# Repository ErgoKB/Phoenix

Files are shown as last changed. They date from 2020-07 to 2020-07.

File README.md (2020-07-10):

# Phoenix

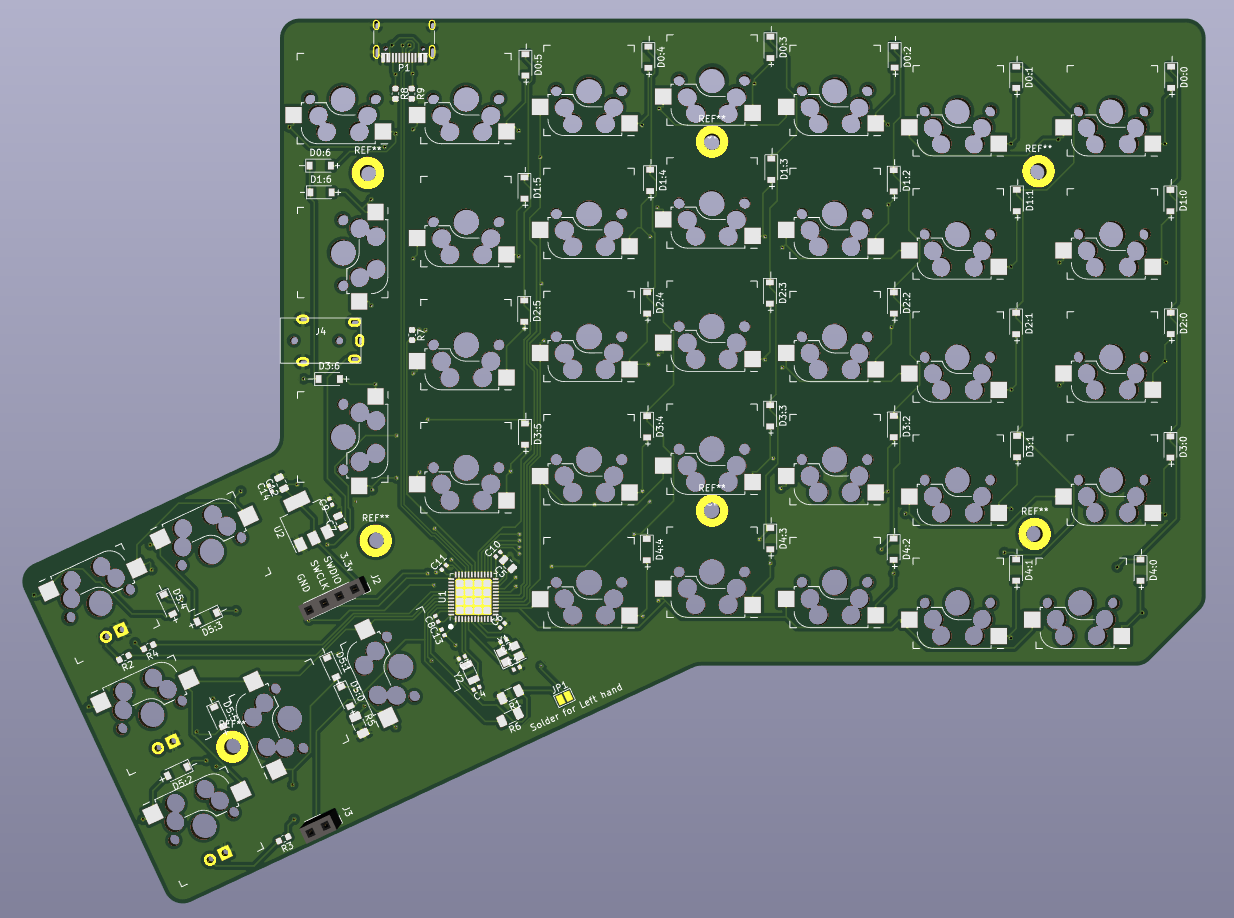
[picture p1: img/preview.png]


Phoenix is inspired by [Ergodox](https://www.ergodox.io/), and add several improvements on it.

## Features

* A split ergonomic keyboard which fits the shape of the hands of human
* Improve the keyboard performance and response time of Ergodox by using dual controller
* Dual connectivity of both left and right hands can connect to USB host without re-program the mcu
* Use USB C connectors
* Use hotswap switch connectors to get rid of soldering
* A single PCB design for both left and right hand
* A more stable PCB mounting design
* Use parts that are can be obtained more easily

## How to build

Still in progress

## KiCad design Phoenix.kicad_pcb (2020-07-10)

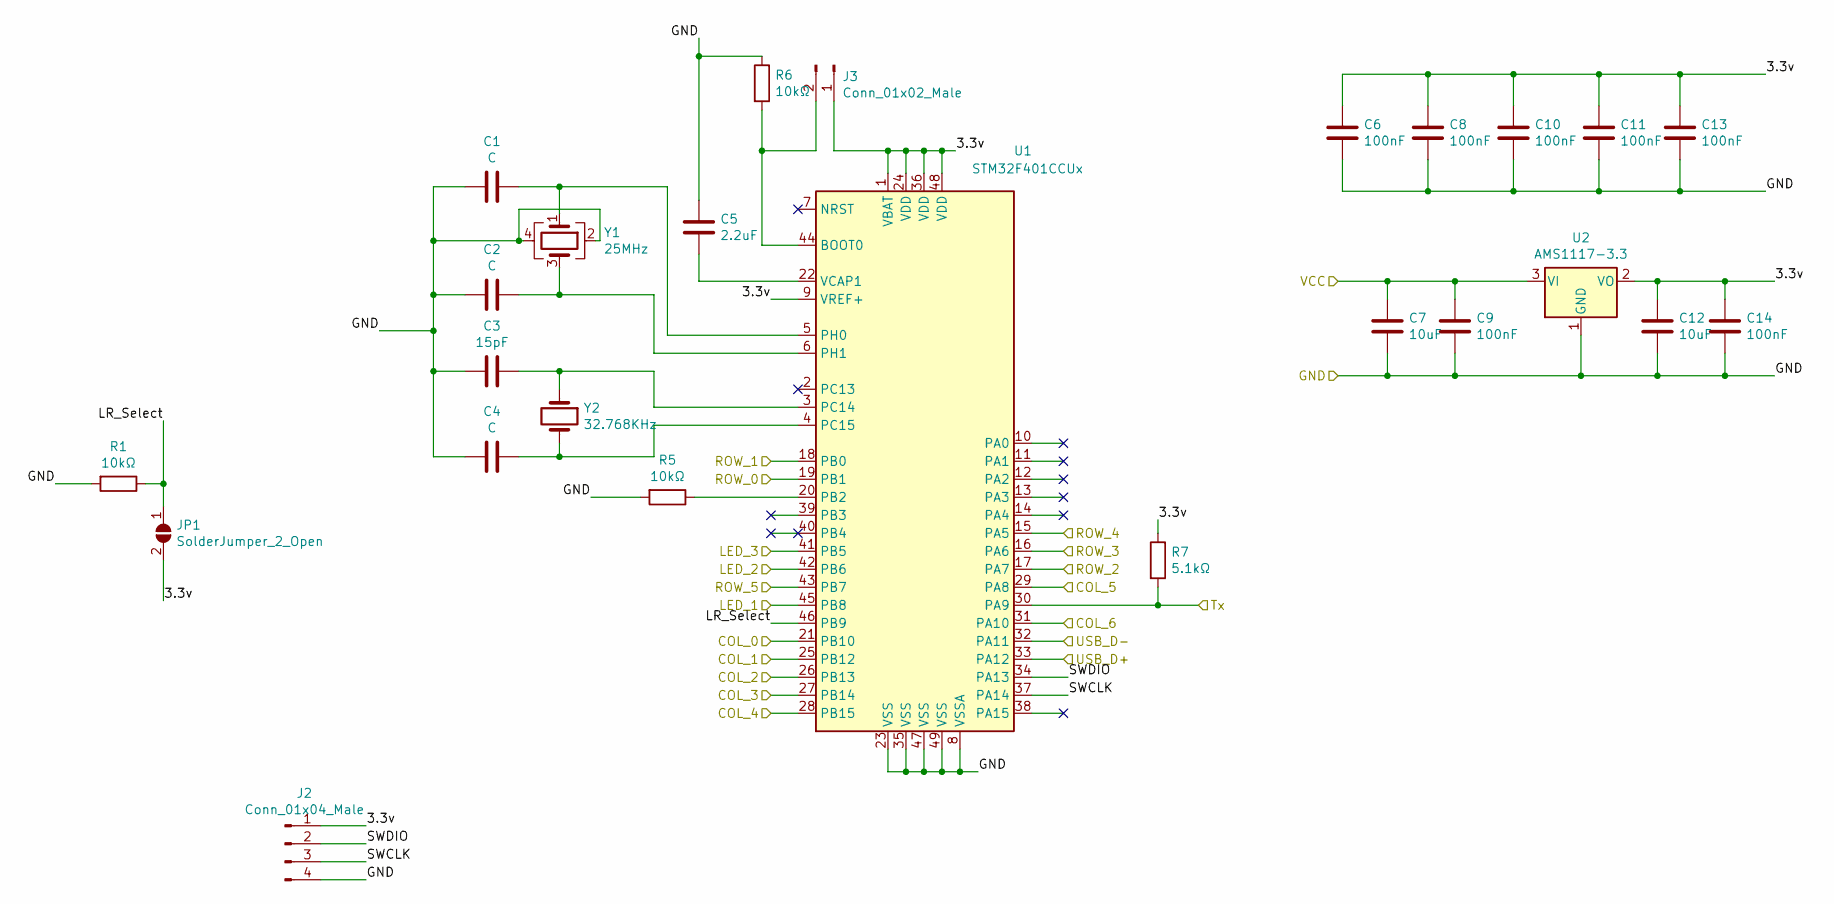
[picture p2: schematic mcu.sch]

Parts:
C1, C2, C4: C; C_0402_1005Metric
C3: 15pF; C_0402_1005Metric
C5: 2.2uF; C_0805_2012Metric
C6, C8, C9, C10, C11, C13, C14: 100nF; C_0402_1005Metric
C7, C12: 10uF; C_0805_2012Metric
J2: Conn_01x04_Male; PinSocket_1x04_P2.54mm_Vertical
J3: Conn_01x02_Male; PinSocket_1x02_P2.54mm_Vertical
JP1: SolderJumper_2_Open; SolderJumper-2_P1.3mm_Open_Pad1.0x1.5mm
R1, R5, R6: 10kΩ; R_1206_3216Metric
R7: 5.1kΩ; R_0603_1608Metric
U1: STM32F401CCUx; QFN-48-1EP_7x7mm_P0.5mm_EP5.6x5.6mm
U2: AMS1117-3.3; SOT-223-3_TabPin2
Y1: 25MHz; Crystal_SMD_3225-4Pin_3.2x2.5mm
Y2: 32.768KHz; Crystal_SMD_3215-2Pin_3.2x1.5mm

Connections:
/TRS/Tx: R7.2, U1.30 (PA9); also elsewhere on the board
/TRS/VCC: C7.1, C9.1, U2.3 (VI); also elsewhere on the board
/keyboard_matrix/COL_0: U1.21 (PB10); also elsewhere on the board
/keyboard_matrix/COL_1: U1.25 (PB12); also elsewhere on the board
/keyboard_matrix/COL_2: U1.26 (PB13); also elsewhere on the board
/keyboard_matrix/COL_3: U1.27 (PB14); also elsewhere on the board
/keyboard_matrix/COL_4: U1.28 (PB15); also elsewhere on the board
/keyboard_matrix/COL_5: U1.29 (PA8); also elsewhere on the board
/keyboard_matrix/COL_6: U1.31 (PA10); also elsewhere on the board
/keyboard_matrix/LED_1: U1.45 (PB8); also elsewhere on the board
/keyboard_matrix/LED_2: U1.42 (PB6); also elsewhere on the board
/keyboard_matrix/LED_3: U1.41 (PB5); also elsewhere on the board
/keyboard_matrix/ROW_0: U1.19 (PB1); also elsewhere on the board
/keyboard_matrix/ROW_1: U1.18 (PB0); also elsewhere on the board
/keyboard_matrix/ROW_2: U1.17 (PA7); also elsewhere on the board
/keyboard_matrix/ROW_3: U1.16 (PA6); also elsewhere on the board
/keyboard_matrix/ROW_4: U1.15 (PA5); also elsewhere on the board
/keyboard_matrix/ROW_5: U1.43 (PB7); also elsewhere on the board
/mcu/3.3v: C6.1, C8.1, C10.1, C11.1, C12.1, C13.1, C14.1, J2.1, J3.1, JP1.2 (B), R7.1, U1.1 (VBAT), U1.9 (VREF+), U1.24 (VDD), U1.36 (VDD), U1.48 (VDD), U2.2 (VO)
/mcu/LR_Select: JP1.1 (A), R1.1, U1.46 (PB9)
/mcu/SWCLK: J2.3, U1.37 (PA14)
/mcu/SWDIO: J2.2, U1.34 (PA13)
/usb_c/D+: U1.33 (PA12); also elsewhere on the board
/usb_c/D-: U1.32 (PA11); also elsewhere on the board
GNDPWR: C1.2, C2.2, C3.2, C4.2, C5.2, C6.2, C7.2, C8.2, C9.2, C10.2, C11.2, C12.2, C13.2, C14.2, J2.4, R1.2, R5.2, R6.1, U1.8 (VSSA), U1.23 (VSS), U1.35 (VSS), U1.47 (VSS), U1.49 (VSS), U2.1 (GND), Y1.2, Y1.4; also elsewhere on the board
unnamed: C1.1, U1.5 (PH0), Y1.1
unnamed: C2.1, U1.6 (PH1), Y1.3
unnamed: C3.1, U1.3 (PC14), Y2.1
unnamed: C4.1, U1.4 (PC15), Y2.2
unnamed: C5.1, U1.22 (VCAP1)
unnamed: J3.2, R6.2, U1.44 (BOOT0)
unnamed: R5.1, U1.20 (PB2)

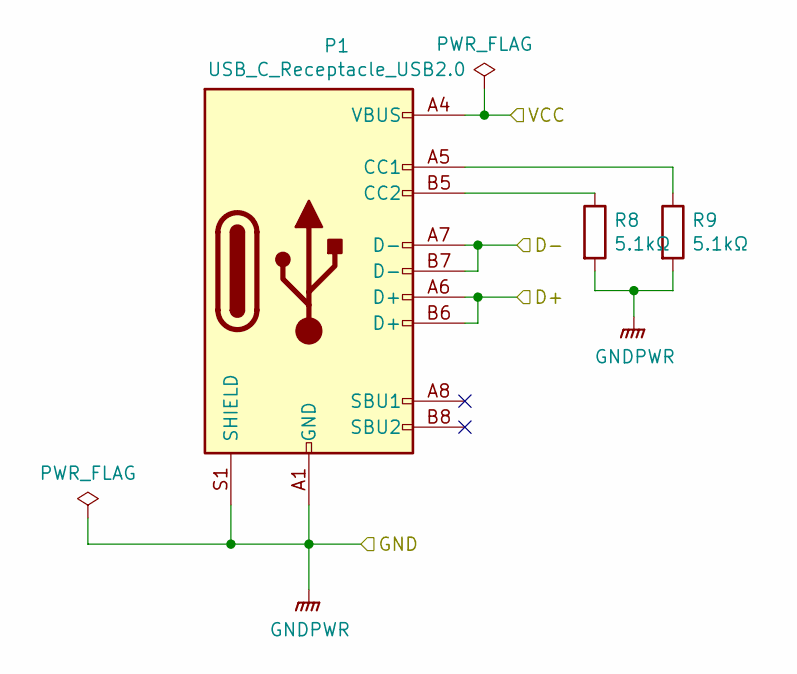
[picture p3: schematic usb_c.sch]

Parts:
P1: USB_C_Receptacle_USB2.0; USB_C_Receptacle_HRO_TYPE-C-31-M-12-Dual
R8, R9: 5.1kΩ; R_0603_1608Metric

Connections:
/TRS/VCC: P1.A4 (VBUS), P1.A9 (VBUS), P1.B4 (VBUS), P1.B9 (VBUS); also elsewhere on the board
/usb_c/D+: P1.A6 (D+), P1.B6 (D+); also elsewhere on the board
/usb_c/D-: P1.A7 (D-), P1.B7 (D-); also elsewhere on the board
GNDPWR: P1.A1 (GND), P1.A12 (GND), P1.B1 (GND), P1.B12 (GND), P1.S1 (SHIELD), R8.2, R9.2; also elsewhere on the board
unnamed: P1.A5 (CC1), R9.1
unnamed: P1.B5 (CC2), R8.1

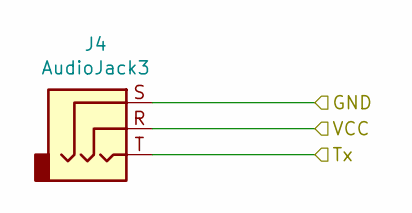
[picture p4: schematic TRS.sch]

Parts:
J4: AudioJack3; PJ322_TRS

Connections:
/TRS/Tx: J4.T; also elsewhere on the board
/TRS/VCC: J4.R; also elsewhere on the board
GNDPWR: J4.S; also elsewhere on the board

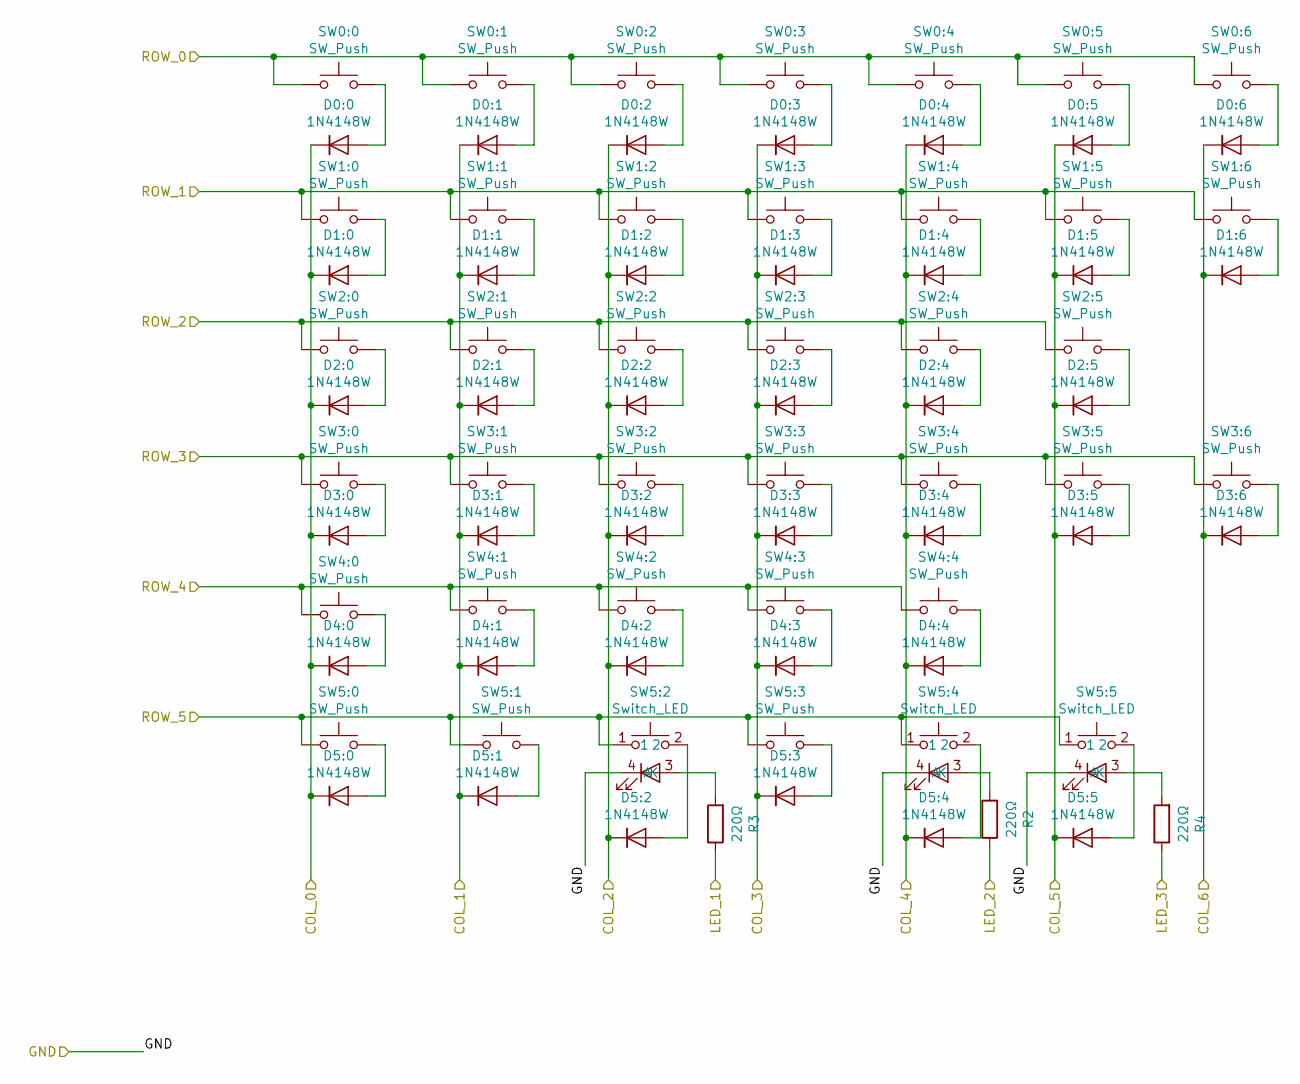
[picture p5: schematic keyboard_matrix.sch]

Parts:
D0:0, D0:1, D0:2, D0:3, D0:4, D0:5, D0:6, D1:0, D1:1, D1:2, D1:3, D1:4, D1:5, D1:6, D2:0, D2:1, D2:2, D2:3, D2:4, D2:5, D3:0, D3:1, D3:2, D3:3, D3:4, D3:5, D3:6, D4:0, D4:1, D4:2, D4:3, D4:4, D5:0, D5:1, D5:2, D5:3, D5:4, D5:5: 1N4148W; D_SOD-123
R2, R3, R4: 220Ω; R_0603_1608Metric
SW0:0, SW0:1, SW0:2, SW0:3, SW0:4, SW0:5, SW0:6, SW1:0, SW1:1, SW1:2, SW1:3, SW1:4, SW1:5, SW1:6, SW2:0, SW2:1, SW2:2, SW2:3, SW2:4, SW2:5, SW3:0, SW3:1, SW3:2, SW3:3, SW3:4, SW3:5, SW3:6, SW4:0, SW4:1, SW4:2, SW4:3, SW4:4, SW5:0, SW5:1, SW5:3: SW_Push; Kailh_hot_socket_MX_dual
SW5:2, SW5:4, SW5:5: Switch_LED; Kailh_hot_socket_MX_dual_led

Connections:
/keyboard_matrix/COL_0: D0:0.1 (K), D1:0.1 (K), D2:0.1 (K), D3:0.1 (K), D4:0.1 (K), D5:0.1 (K); also elsewhere on the board
/keyboard_matrix/COL_1: D0:1.1 (K), D1:1.1 (K), D2:1.1 (K), D3:1.1 (K), D4:1.1 (K), D5:1.1 (K); also elsewhere on the board
/keyboard_matrix/COL_2: D0:2.1 (K), D1:2.1 (K), D2:2.1 (K), D3:2.1 (K), D4:2.1 (K), D5:2.1 (K); also elsewhere on the board
/keyboard_matrix/COL_3: D0:3.1 (K), D1:3.1 (K), D2:3.1 (K), D3:3.1 (K), D4:3.1 (K), D5:3.1 (K); also elsewhere on the board
/keyboard_matrix/COL_4: D0:4.1 (K), D1:4.1 (K), D2:4.1 (K), D3:4.1 (K), D4:4.1 (K), D5:4.1 (K); also elsewhere on the board
/keyboard_matrix/COL_5: D0:5.1 (K), D1:5.1 (K), D2:5.1 (K), D3:5.1 (K), D5:5.1 (K); also elsewhere on the board
/keyboard_matrix/COL_6: D0:6.1 (K), D1:6.1 (K), D3:6.1 (K); also elsewhere on the board
/keyboard_matrix/LED_1: R3.1; also elsewhere on the board
/keyboard_matrix/LED_2: R2.1; also elsewhere on the board
/keyboard_matrix/LED_3: R4.1; also elsewhere on the board
/keyboard_matrix/ROW_0: SW0:0.1, SW0:1.1, SW0:2.1, SW0:3.1, SW0:4.1, SW0:5.1, SW0:6.1; also elsewhere on the board
/keyboard_matrix/ROW_1: SW1:0.1, SW1:1.1, SW1:2.1, SW1:3.1, SW1:4.1, SW1:5.1, SW1:6.1; also elsewhere on the board
/keyboard_matrix/ROW_2: SW2:0.1, SW2:1.1, SW2:2.1, SW2:3.1, SW2:4.1, SW2:5.1; also elsewhere on the board
/keyboard_matrix/ROW_3: SW3:0.1, SW3:1.1, SW3:2.1, SW3:3.1, SW3:4.1, SW3:5.1, SW3:6.1; also elsewhere on the board
/keyboard_matrix/ROW_4: SW4:0.1, SW4:1.1, SW4:2.1, SW4:3.1, SW4:4.1; also elsewhere on the board
/keyboard_matrix/ROW_5: SW5:0.1, SW5:1.1, SW5:2.1, SW5:3.1, SW5:4.1, SW5:5.1; also elsewhere on the board
GNDPWR: SW5:2.4 (K), SW5:4.4 (K), SW5:5.4 (K); also elsewhere on the board
unnamed: D0:0.2 (A), SW0:0.2
unnamed: D0:1.2 (A), SW0:1.2
unnamed: D0:2.2 (A), SW0:2.2
unnamed: D0:3.2 (A), SW0:3.2
unnamed: D0:4.2 (A), SW0:4.2
unnamed: D0:5.2 (A), SW0:5.2
unnamed: D0:6.2 (A), SW0:6.2
unnamed: D1:0.2 (A), SW1:0.2
unnamed: D1:1.2 (A), SW1:1.2
unnamed: D1:2.2 (A), SW1:2.2
unnamed: D1:3.2 (A), SW1:3.2
unnamed: D1:4.2 (A), SW1:4.2
unnamed: D1:5.2 (A), SW1:5.2
unnamed: D1:6.2 (A), SW1:6.2
unnamed: D2:0.2 (A), SW2:0.2
unnamed: D2:1.2 (A), SW2:1.2
unnamed: D2:2.2 (A), SW2:2.2
unnamed: D2:3.2 (A), SW2:3.2
unnamed: D2:4.2 (A), SW2:4.2
unnamed: D2:5.2 (A), SW2:5.2
unnamed: D3:0.2 (A), SW3:0.2
unnamed: D3:1.2 (A), SW3:1.2
unnamed: D3:2.2 (A), SW3:2.2
unnamed: D3:3.2 (A), SW3:3.2
unnamed: D3:4.2 (A), SW3:4.2
unnamed: D3:5.2 (A), SW3:5.2
unnamed: D3:6.2 (A), SW3:6.2
unnamed: D4:0.2 (A), SW4:0.2
unnamed: D4:1.2 (A), SW4:1.2
unnamed: D4:2.2 (A), SW4:2.2
unnamed: D4:3.2 (A), SW4:3.2
unnamed: D4:4.2 (A), SW4:4.2
unnamed: D5:0.2 (A), SW5:0.2
unnamed: D5:1.2 (A), SW5:1.2
unnamed: D5:2.2 (A), SW5:2.2
unnamed: D5:3.2 (A), SW5:3.2
unnamed: D5:4.2 (A), SW5:4.2
unnamed: D5:5.2 (A), SW5:5.2
unnamed: R2.2, SW5:4.3 (A)
unnamed: R3.2, SW5:2.3 (A)
unnamed: R4.2, SW5:5.3 (A)

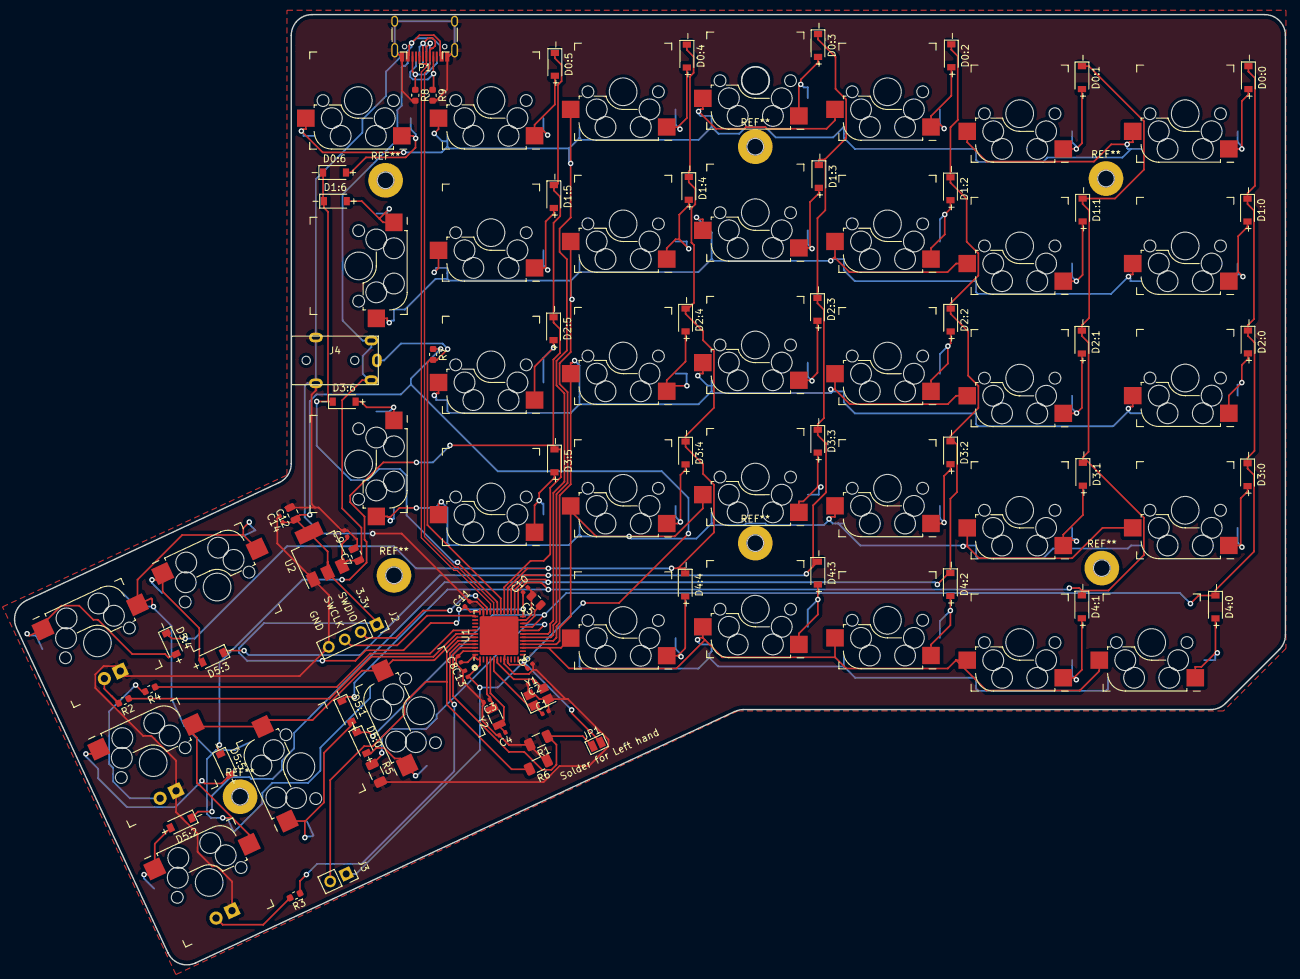
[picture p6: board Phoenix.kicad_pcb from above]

Board: 2 copper layers, 183.2 x 137.0 mm, 108 parts (0 on the bottom side), 75 nets.
